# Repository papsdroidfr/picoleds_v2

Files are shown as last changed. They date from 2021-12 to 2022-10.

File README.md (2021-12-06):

# picoleds_v2

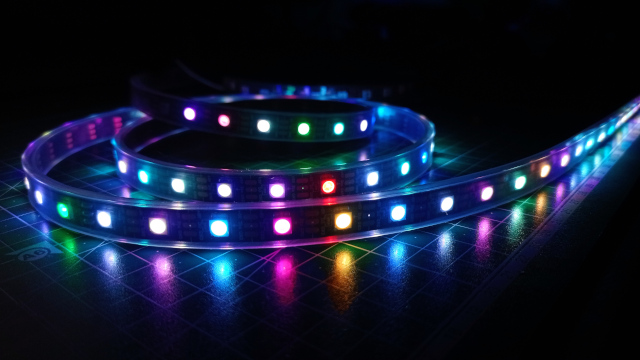
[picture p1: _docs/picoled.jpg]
picoleds


Ruban de leds RGB commandé par un Raspberry PICO

## Electronique

### schéma sur platine d'essai
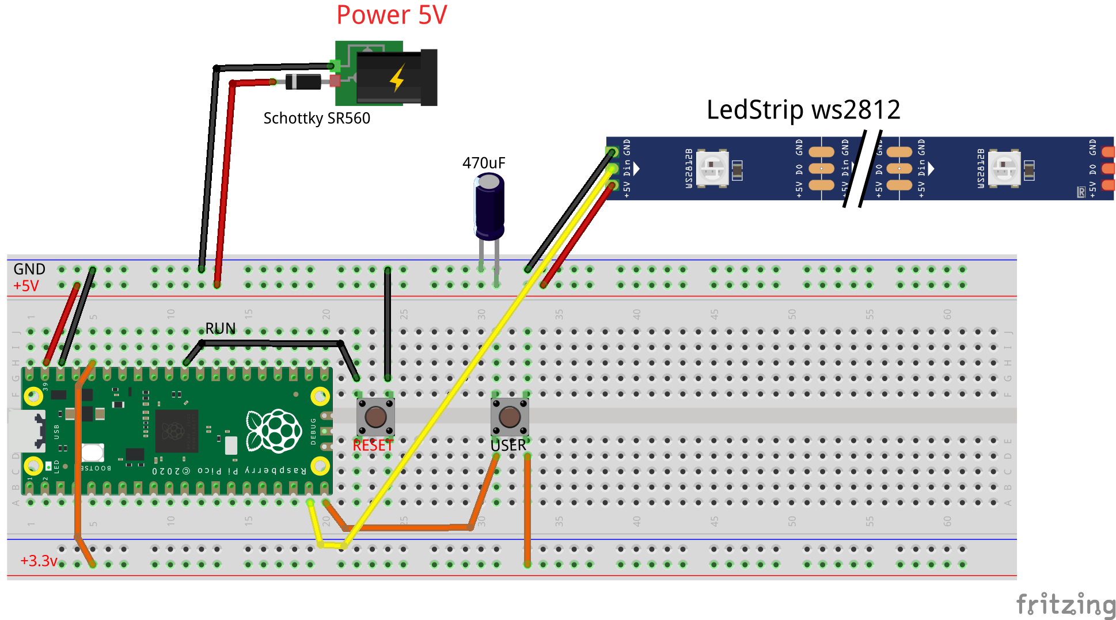
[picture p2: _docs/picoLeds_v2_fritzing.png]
fritzing

Un bouton poussoir (RESET) sert à faire un reset du circuit pour pouvoir reprogrammer le microcontrôleur par exemple.
L'autre bouton poussoir (USR) sert à modifier les animations. La diode Shottky SR560 est nécessaire si vous branchez le câble micro-usb en même temps que l'alimentation externe 5v: elle sert à éviter que les alimentations se "percuttent".

### Circuit imprimé
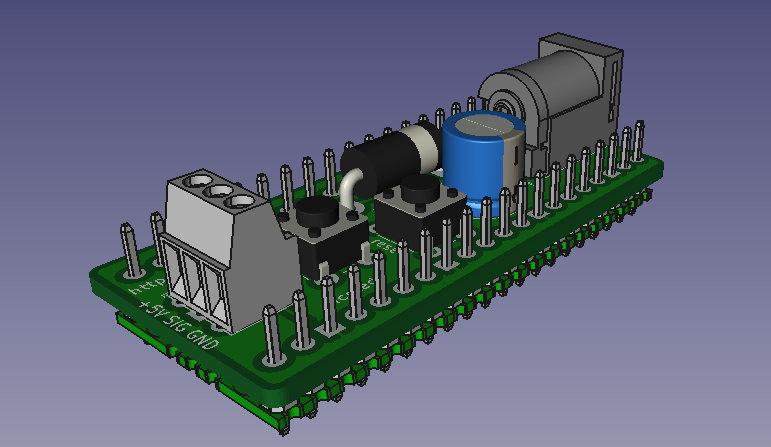
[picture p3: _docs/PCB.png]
PCB


Un PCB peut être commandé chez n'importe quel fabriquant de PCB en utilisant les fichier GERBER dans le dossier **/KICAD_GERBER**

### Matériel nécessaire:
* un rapsberry PICO avec 2 rangées de 20 PIN Header soudées
* une diode shottkey SR560
* un petit bornier à souder 3pin 2.54mm (pour y brancher les 3 fils du ruban de leds)
* un condensateur polarisé 470uF
* une prise Jack à souder
* une alimentation 5v-2A Jack (si plus de 100 leds: prendre 3A)
* 2 petits boutons poussoir 6mm à souder
* Un ruban de leds RGB WS2812 (au delà de 100 leds il faudra envisager une alimentation 5v de 3A)

Le Raspberry PICO se soude par dessous le PCB (en tout dernier) la sortie USB est dans le même sens que la prise JACK, tout le reste se soude au-dessus.

### Impression 3D
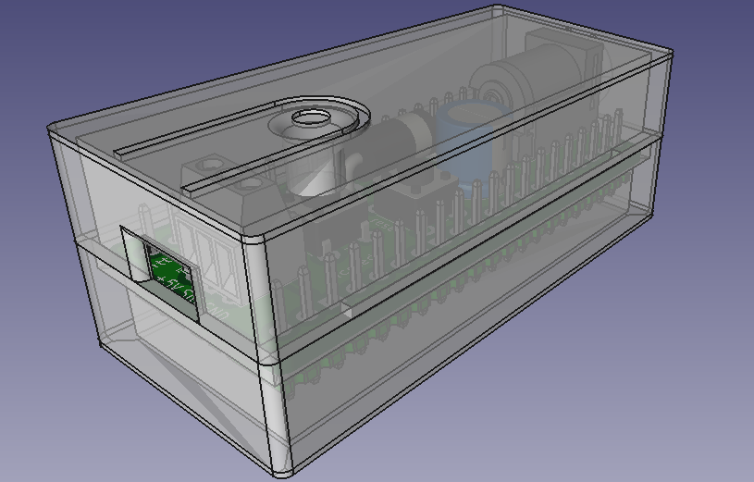
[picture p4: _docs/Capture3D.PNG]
3D


Un boitier en 2 parties haute et basse compatible avec le PCB peut être imprimé en 3D.
les fichiers STL sont dans le dossier /STL.
Les deux éléments s'impriment face pleine vers le bas.
Seule la partie basse nécessite des supports à cause de l'ouverture USB du raspberry PICO

## Scripts Micro-python

Si vous configurez votre Raspberry PICO pour la première fois, suivez [ce guide](https://www.papsdroid.fr/post/hello-pico)

Les scripts micropython se trouvent dans le répertoire **/micropython** de ce Github.

Il faut installer la bibliothèque **ledRGBws2812.py** à la racine du PICO.
Ensuite vous avez deux programmes distincts selon l'ambiance que vous souhaitez obtenir:

* ambiance type guirlande de Noël: **main.noel.py**
* ambiance zen décontractée: **main_chill.py**

Choissiez l'un ou l'autre et renommez-le **main.py**, à deposer à la racine du PICO, ainsi il sera automatiquement exécutée au démarrage du PICO.

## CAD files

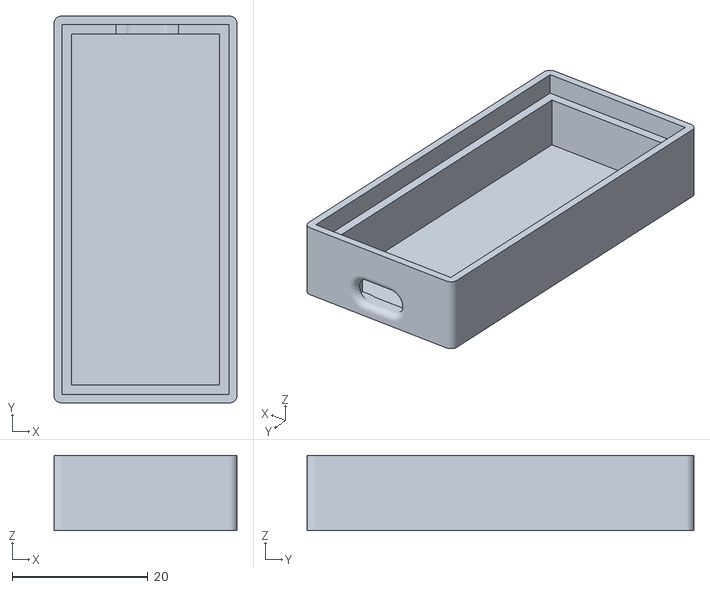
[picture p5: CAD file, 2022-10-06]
STL/picoledv2-Part_BOITIERBody_bas.stl
26.9 x 56.9 x 11.1

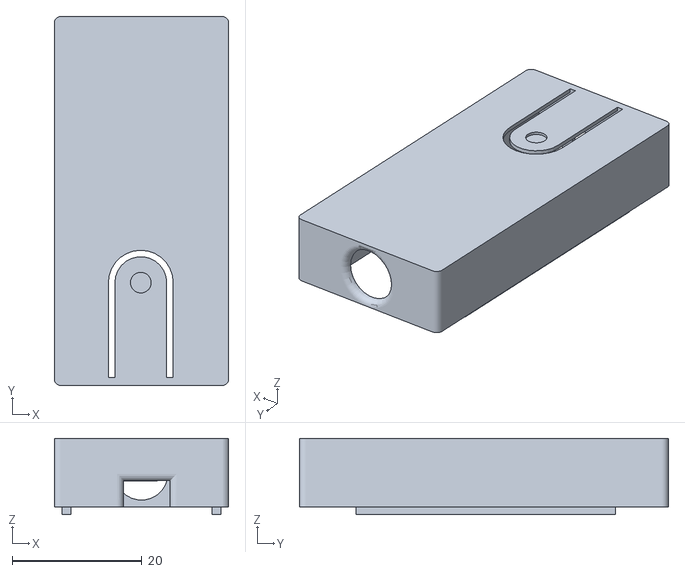
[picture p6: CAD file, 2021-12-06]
STL/picoledv2-Part_BOITIERBody_haut.stl
26.9 x 56.9 x 11.8

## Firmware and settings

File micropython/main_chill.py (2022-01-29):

#RUNS ON PICO
from ledRGBws2812 import LedsRGBws2812
from machine import Pin
import time

class Application:
    
    def __init__(self):
        ''' initialize leds RGB and push Button'''
        self.ledStatus = Pin(25, Pin.OUT)     # led témoin du pico
        self.leds = LedsRGBws2812(pin_num=14, n_leds=80, brightness=0.2)  # ruban de leds 
        self.button = Pin(15, Pin.IN, Pin.PULL_DOWN) #bouton poussoir avec resistance de rappel activée
        self.leds.pixels_off()
        self.id_anim=0
        self.l_anims = ['mono_wheel', 'rainbow_cycle', 'random', 'fill', 'fill', 'off']
        self.leds.animation = self.l_anims[0]
        self.bouncetime = 0.05 #stabilization period with push button
        #callback function called with push button
        self.button.irq(self.callback, Pin.IRQ_FALLING)
        self.buttonPressed = False #button not pressed
        self.ledStatus.value(1)
        self.loop()  #inifinite loop of events     
    
    def callback(self, pin):
        ''' callback function called when buton is pushed '''
        time.sleep(self.bouncetime)  # wait stabilization to avoid rebounds.
        if not(self.button.value()): # push button still pressed after the stabilization period ?
            if (self.buttonPressed == False) : # run only 1 time the callback
                
                self.buttonPressed = True
                
                self.id_anim = (self.id_anim+1) % len(self.l_anims)
                self.leds.animation = self.l_anims[self.id_anim] #name animation change
                self.ledStatus.value(1)
                print('button pressed', pin.irq().flags())
                print('animation: ', self.leds.animation)
                
                #transition to play
                if self.id_anim==0:
                    pass
                elif self.id_anim==1:
                    pass
                elif self.id_anim==2:
                    pass
                elif self.id_anim==3:
                    self.leds.fade_in(10, self.leds.BLUE, 0.05)
                elif self.id_anim==4:
                    self.leds.fade_out(10, self.leds.BLUE, 0.05)
                    self.leds.fade_in(10, self.leds.PURPLE, 0.05)
                else:
                    self.leds.fade_out(10, self.leds.PURPLE, 0.05)
                    self.ledStatus.value(0)         
    
    def loop(self):
        while(True):
            self.buttonPressed = False
            if self.id_anim==0:
                self.leds.mono_wheel(delay=0.5)
            elif self.id_anim==1:
                self.leds.rainbow_cycle()
            elif self.id_anim==2:
                self.leds.random(green=False)
            elif self.id_anim==3:
                self.leds.pixels_fill(self.leds.BLUE)
                time.sleep(0.5)
            elif self.id_anim==4:
                self.leds.pixels_fill(self.leds.PURPLE)
                time.sleep(0.5)
            else:
                self.leds.pixels_fill(self.leds.BLACK)
                time.sleep(0.5)

appl=Application()

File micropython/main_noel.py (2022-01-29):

#RUNS ON PICO
from ledRGBws2812 import LedsRGBws2812
from machine import Pin
import time, machine

class Application:
    
    def __init__(self):
        ''' initialize leds RGB and push Button'''
        self.ledStatus = Pin(25, Pin.OUT)     # led témoin du pico
        self.leds = LedsRGBws2812(pin_num=14, n_leds=48, brightness=0.4)  # ruban de leds 
        self.button = Pin(15, Pin.IN, Pin.PULL_DOWN) #bouton poussoir avec resistance de rappel activée
        self.leds.pixels_off()
        self.leds.animation = ''
        #callback function called with push button
        self.button.irq(self.callback, Pin.IRQ_FALLING)
        self.ledStatus.value(1)
        self.loop()  #inifinite loop of events     
    
    def callback(self, pin):
        ''' callback function called when buton is pushed '''
        time.sleep(0.05) # wait 50ms : stabilization to avoid rebounds.
        if not(self.button.value()): # buton still pressed after the stabilization period ?
            self.ledStatus.value(0)
            machine.reset()
    
    def anim_cool_clignotante(self, nb_repet=1):
        for i in range(nb_repet):
            #anim wheel fade in
            self.leds.fade_wheel(wait=0.02)
            self.leds.pixels_off()
            self.leds.shuffle_wheel(wait=0.02)
            self.leds.pixels_off()
 
            #anim random fade out, sans rouge
            self.leds.fade_in(n_steps=20, color=(0,127,127) )
            self.leds.fade_out(n_steps=20, color=(0,127,127) )
            self.leds.shuffle_random(red=False, wait=0.02)  
            
            #anim random fade out, sans vert
            self.leds.fade_in(n_steps=20, color=(127,0,127), wait=0.02 )
            self.leds.fade_out(n_steps=20, color=(127,0,127), wait=0.02 )
            self.leds.shuffle_random(green=False, wait=0.02)
            
            #anim random fade out, sans bleu
            self.leds.fade_in(n_steps=20, color=(127,127,0), wait=0.02 )
            self.leds.fade_out(n_steps=20, color=(127,127,0),wait=0.02 )
            self.leds.shuffle_random(blue=False, wait=0.02)
            self.leds.pixels_off()
            
    def anim_cool_arc_en_ciel(self, nb_repet=1):
        self.leds.animation='rainbow_cycle'
        for i in range(nb_repet):
            self.leds.rainbow_cycle(wait=0.02)
    
    def anim_cool_random(self, nb_repet=1):
        for i in range(nb_repet):
            for j in range(20):
                self.leds.random()             #couleurs aléatoires pastel
            for j in range(20):
                self.leds.random(red=False)    #couleur aléatoires pastel sans rouge
            for j in range(20):
                self.leds.random(green=False)  #couleurs aléatoires pastel sans vert
            for j in range(20):
                self.leds.random(blue=False)   #couleurs aléatoires pastel sans bleu
    
    def anim_cool_mono_wheel(self, nb_repet=1):
        self.leds.animation='mono_wheel'
        for i in range(nb_repet):
            self.leds.mono_wheel(delay=0.02)
    
    def loop(self):
        while(True):
            self.anim_cool_clignotante(nb_repet=5)
            self.anim_cool_arc_en_ciel(nb_repet=5)
            self.anim_cool_random(nb_repet=5)
            self.anim_cool_mono_wheel(nb_repet=5)  

appl=Application()

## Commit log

2022-01-29 fix rebound issues with push button
    nouvelle version qui corrige un pb avec les faux-rebonds du bouton-poussoir.
    [main_chill.py, main_noel.py]
2022-10-06 correction passage usb
    passage étroit usb partie basse corrigé pour faciliter l’insertion de la carte
    [picoledv2-Part_BOITIERBody_bas.stl]
